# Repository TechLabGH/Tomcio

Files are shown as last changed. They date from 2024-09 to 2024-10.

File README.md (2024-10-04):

# Tomcio
**Film Development Timer/Controller/Helper**

The project has been built to help me in developing 35mm films. This process requires strictly following timeline depending on used chemicals and film recomendations.

It supports four stages (this is set for Ilford Delta 100 / Ilfosol-3 / Ilfostop Stop Bath / Rapid Fixer)

* **Development**

  Initial agitation during first 10 sec - invert tank 4 times. Next repeat this on beginning of every next minute. Total development time is 7:30

  Drain off developer 10 sec before end

* **Stop bath**

  I use 2 min stop bath with 4 tank inversions at the beginning and after 1 min

* **Fix**

  This is 4 min process - agitation is the same as in development.

* **Rinse**

  This is three step process - fill with water, invert tank 5 timex / replace water, invert 10 times / replace water, invert 20 times

Project use NEMA motor to invert tank. I built 3D printed mount where tank may be quickly and securely attached. I used 6 x 200mm 2020 profiles to build frame. Additionally there is vibration motor attached - it's running at the end of agitation to remove any bubles from film surface.

<a href="https://github.com/TechLabGH/Tomcio/blob/main/PCB/PCB%20design.html" target="blank">Here</a> is interactive PCB document with BOM. Download it and open from local disk.

Hardware/Software:
* <a href="https://www.amazon.com/dp/B0CKRJ81B5" target="blank">TFT Display</a> = 4.0 Inches 480x320 TFT Touch Screen LCD Display Module SPI ST7796S
* ESP32-S3-WROOM-1U-N16R8CT-ND

Software developed in PlatformIO with Arduino framework - libraries needed:
* bodmer/TFT_eSPI@^2.5.43
* laurb9/StepperDriver@^1.4.1

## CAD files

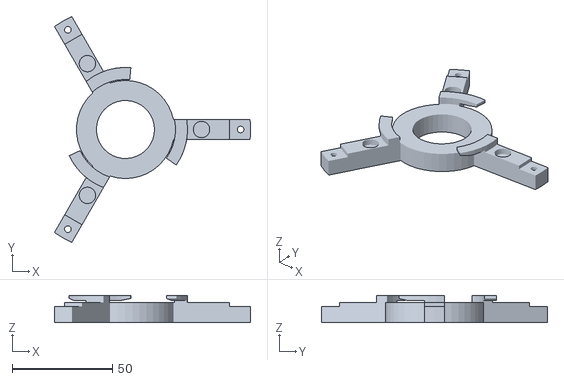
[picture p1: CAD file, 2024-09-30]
3D models/bottom.STL
98.0 x 112.9 x 13.5

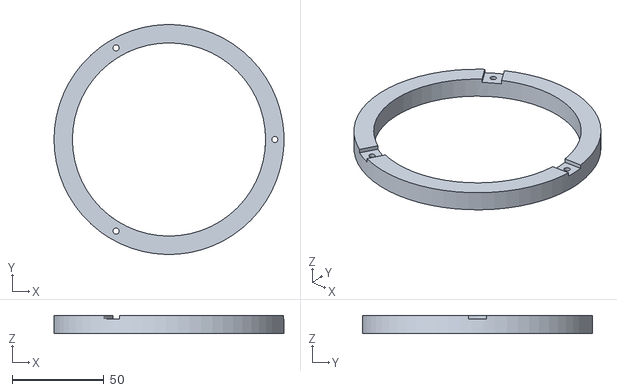
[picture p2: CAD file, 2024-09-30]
3D models/top.STL
125.0 x 125.0 x 10.0

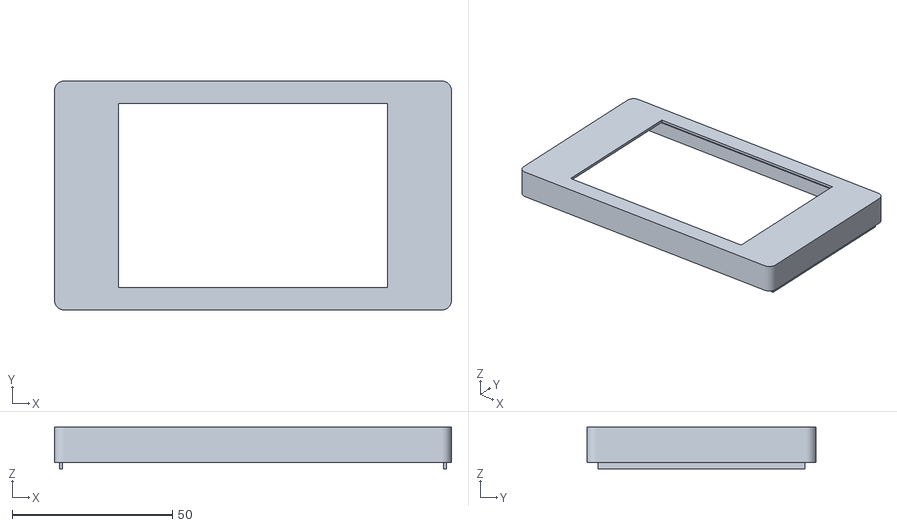
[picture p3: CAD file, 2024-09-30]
3D models/case_1.STL
124.0 x 71.5 x 13.0

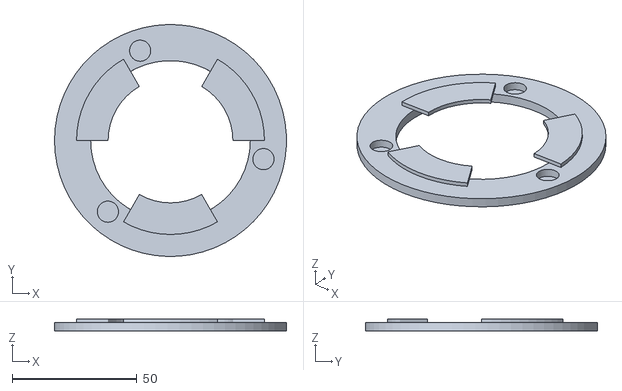
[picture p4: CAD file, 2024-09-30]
3D models/koreks.STL
93.0 x 93.0 x 5.00

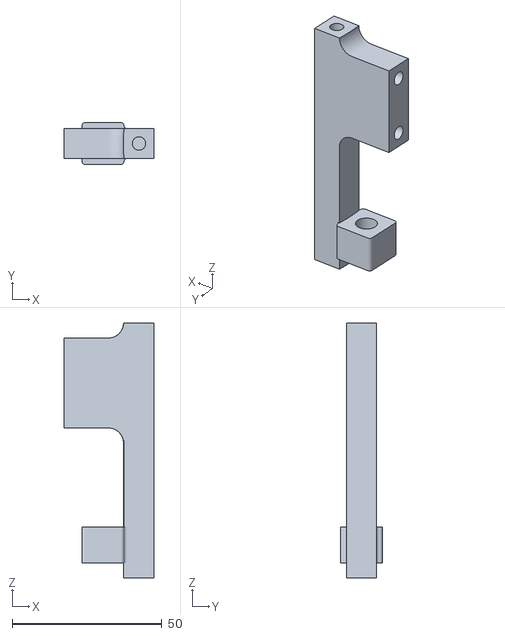
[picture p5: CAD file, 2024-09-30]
3D models/side2.STL
30.0 x 14.0 x 85.0

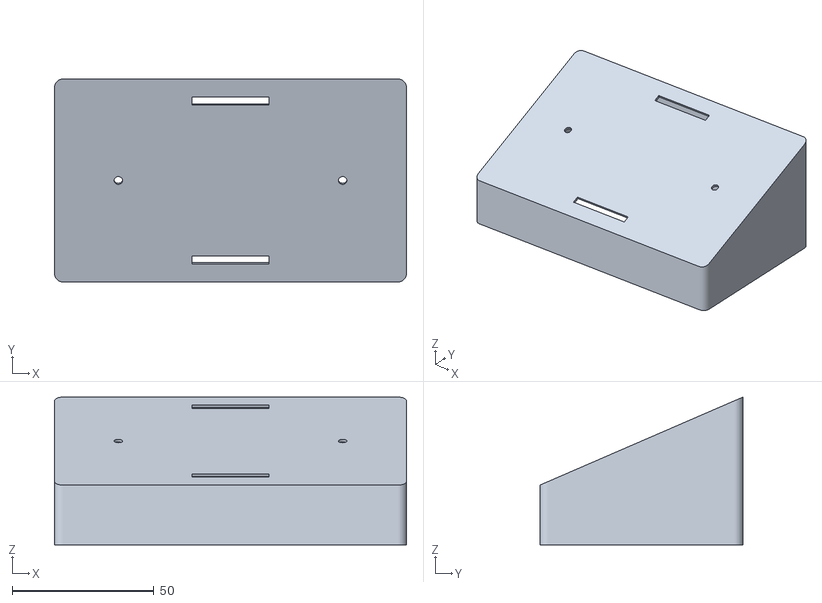
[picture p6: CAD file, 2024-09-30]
3D models/case_2.STL
124.0 x 71.5 x 52.1

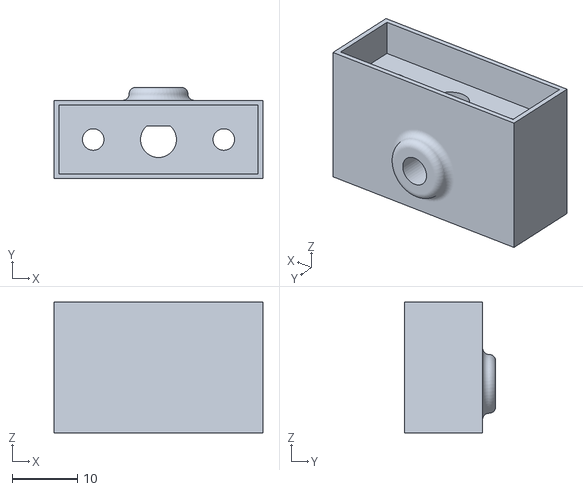
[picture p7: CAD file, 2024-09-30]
3D models/mount.STL
32.0 x 14.0 x 20.0

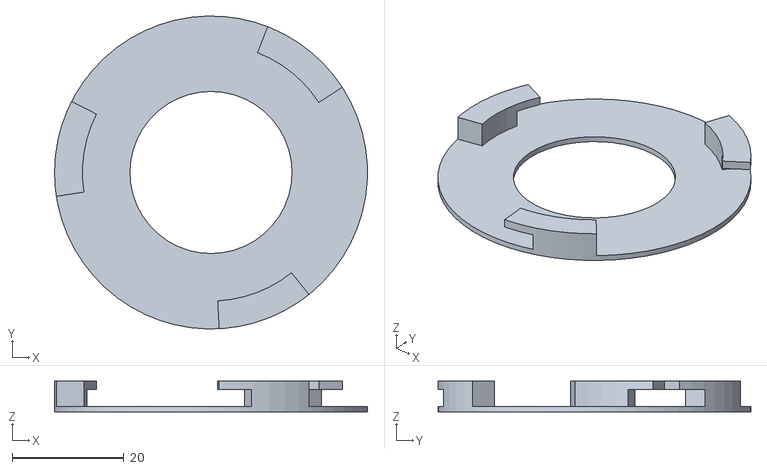
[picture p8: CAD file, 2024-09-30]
3D models/uchwyt.STL
56.0 x 56.0 x 5.50

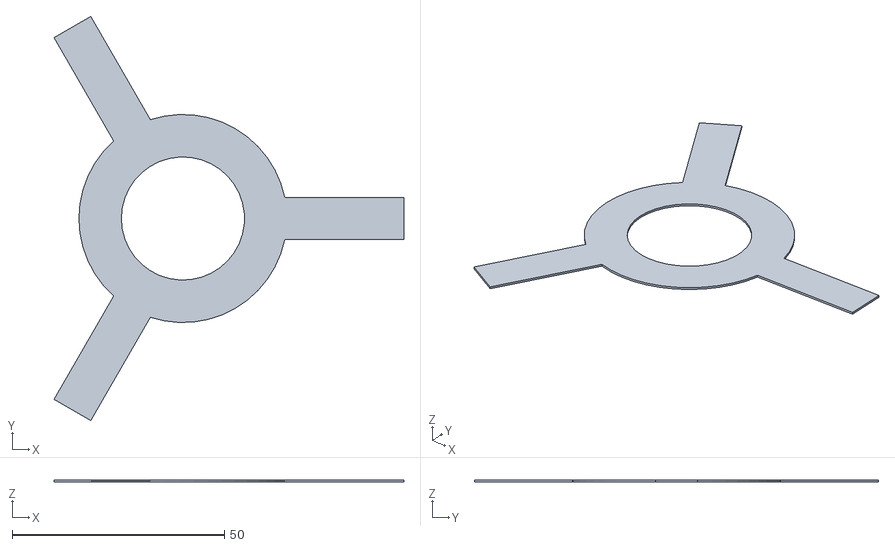
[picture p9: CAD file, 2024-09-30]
3D models/bottom_cover.STL
82.4 x 95.2 x 0.5

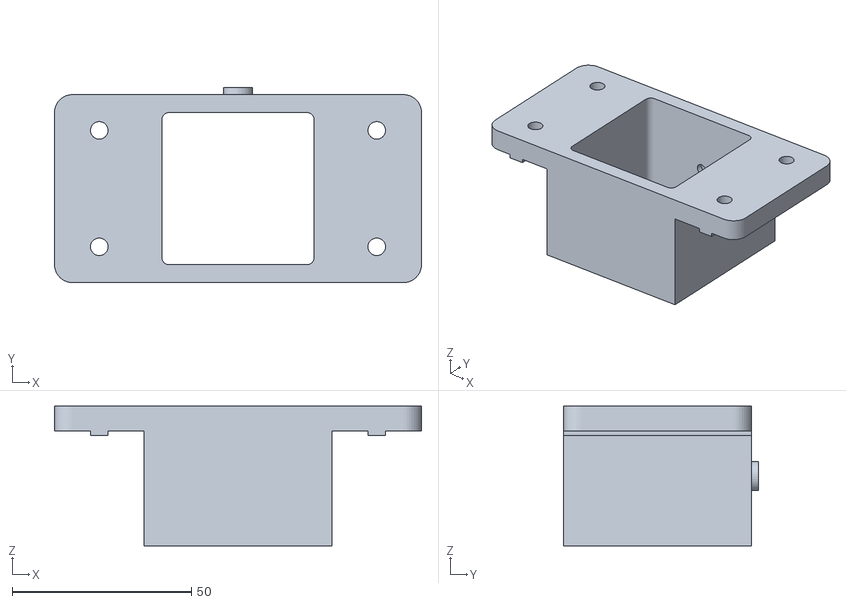
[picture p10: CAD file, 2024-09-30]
3D models/nema_mount.STL
102.5 x 54.5 x 39.0

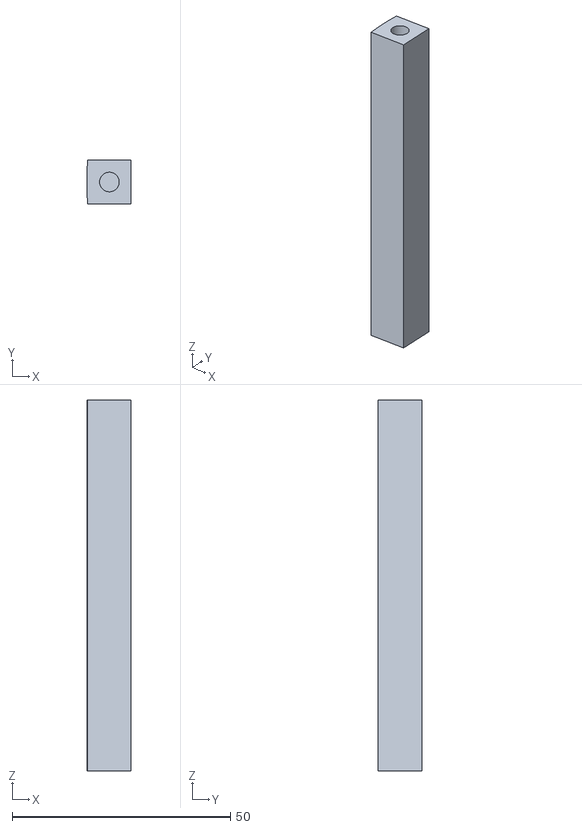
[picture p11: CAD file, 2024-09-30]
3D models/side1.STL
10.2 x 10.0 x 85.0

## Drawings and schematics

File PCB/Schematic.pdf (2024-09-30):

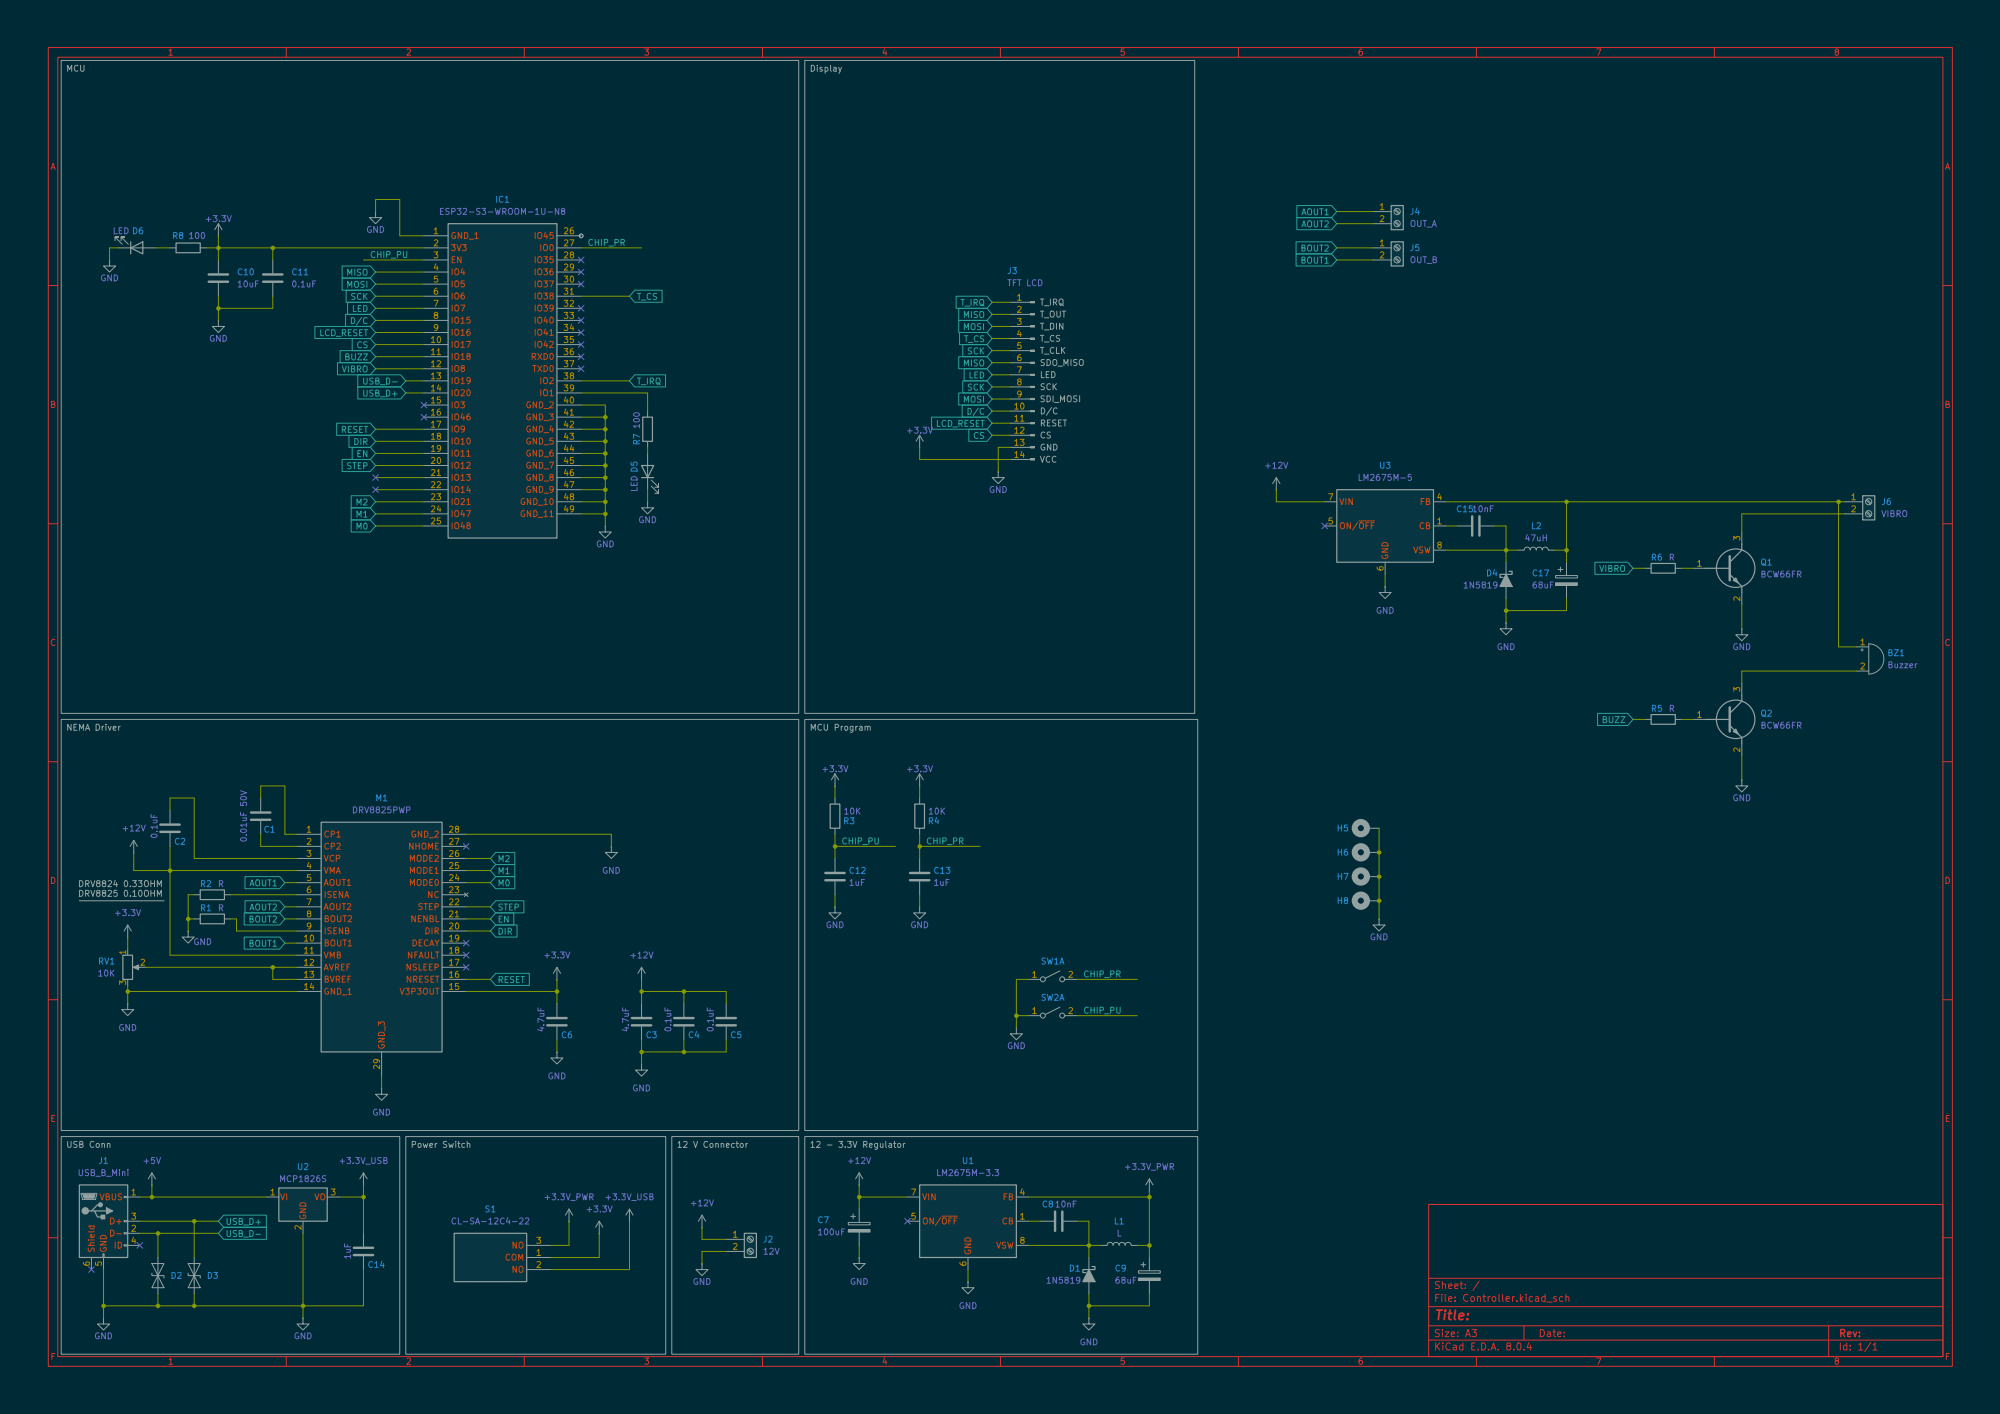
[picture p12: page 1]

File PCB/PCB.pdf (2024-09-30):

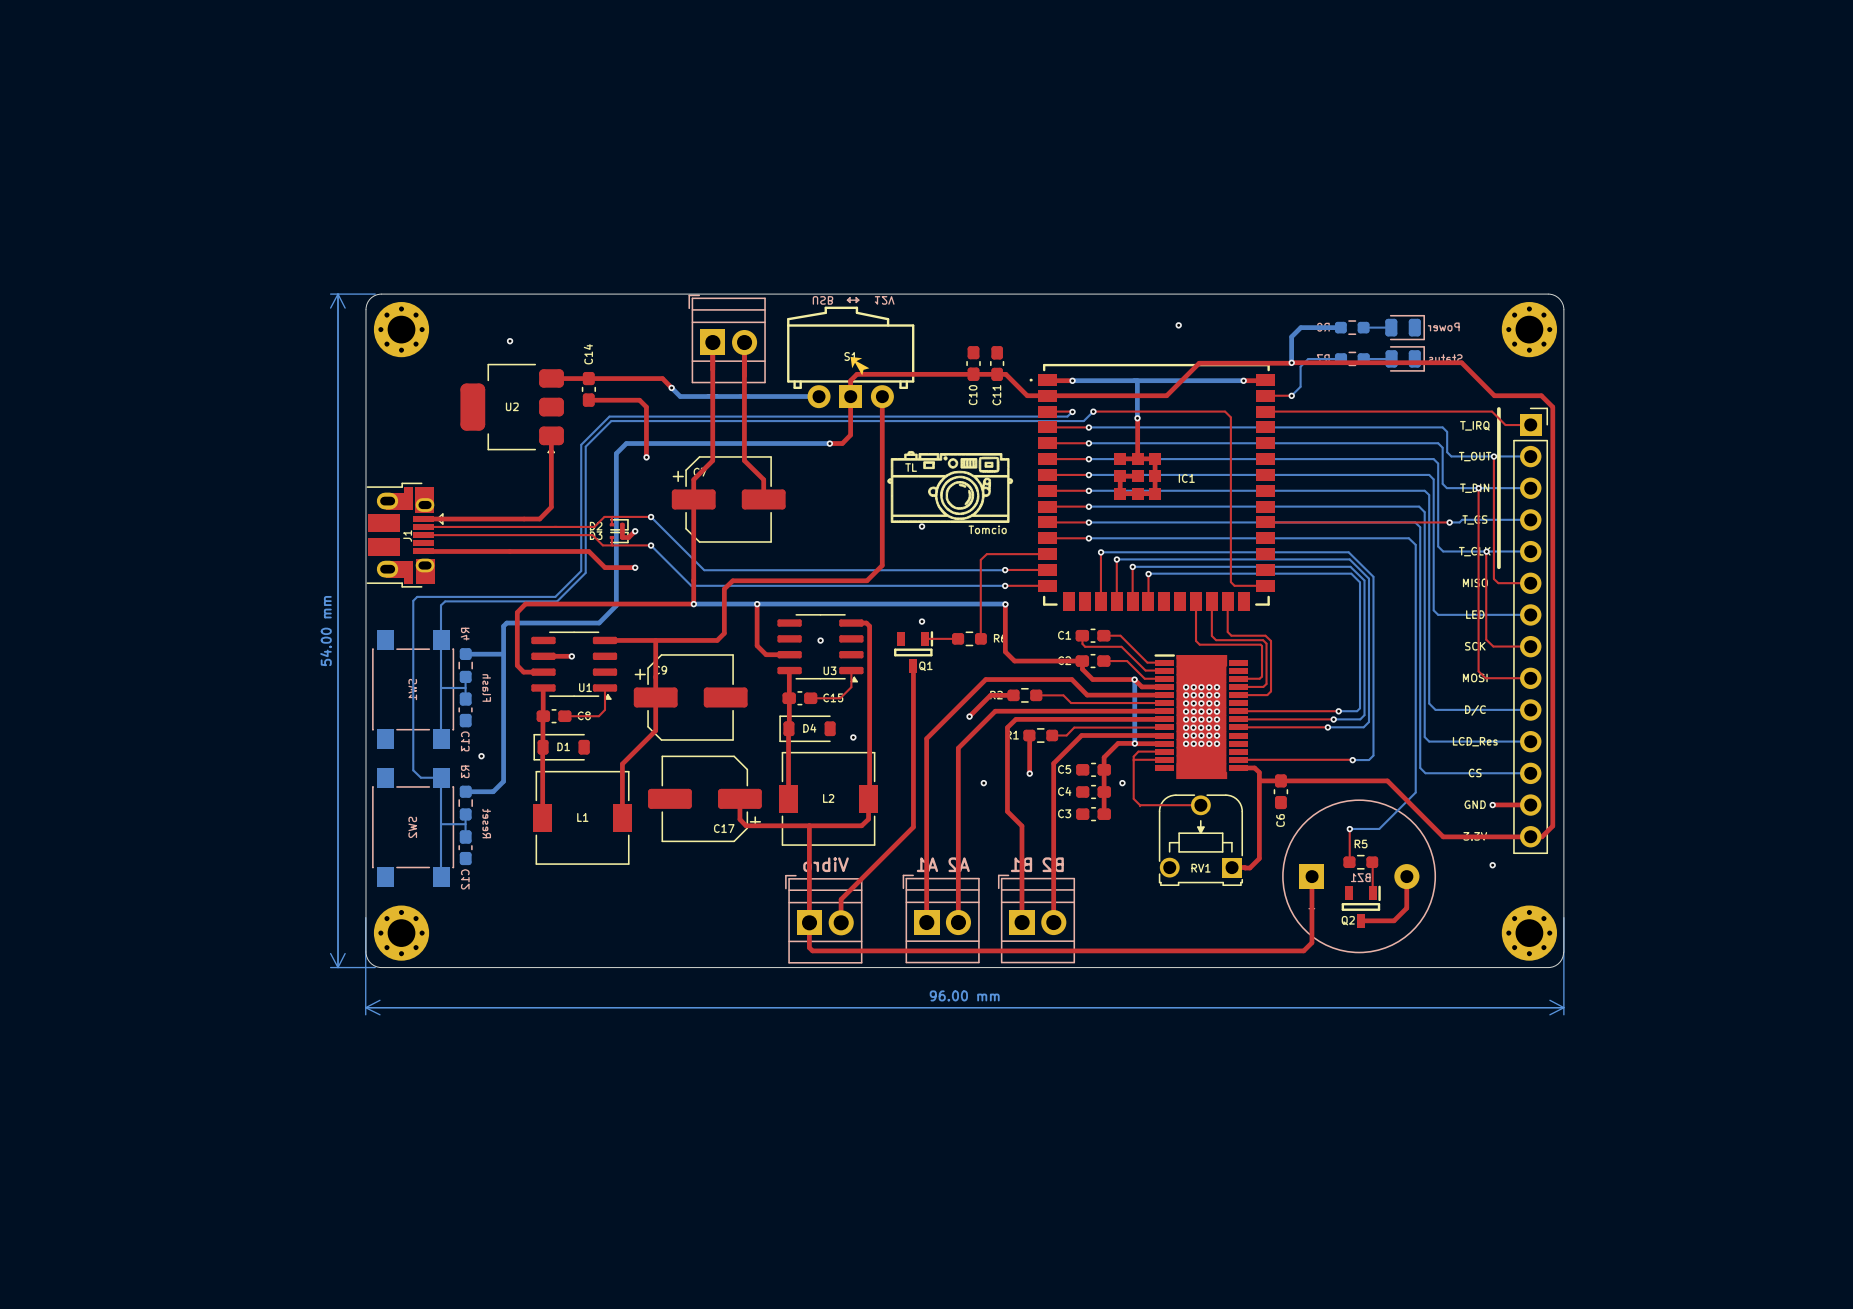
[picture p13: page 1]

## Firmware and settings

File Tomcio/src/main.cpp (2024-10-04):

#include <Arduino.h>
#include "FS.h"
#include <SPI.h>
#include <TFT_eSPI.h>    
#include "Free_Fonts.h"

TFT_eSPI tft = TFT_eSPI(); 

uint16_t prog_data[9][17];                       // Programs data
uint8_t sel_p;                                   // Selected program
uint32_t scale;                                  // Scale to display progress maker
unsigned long startTime;                         // Timestamp when step was started
unsigned long endTime;                           // Timestamp when step will end
unsigned long agitTime;                          // Timestamp of next agitation
unsigned long curr_time;                         // Curr time to calc display progress maker
uint8_t vibro = 0;                               // controlls vibration

#define CALIBRATION_FILE "/TouchCalData2"        // Calibration file
#define REPEAT_CAL false                         // Setting True will run calibration every time

//---------------------------------Stepper driver---------------------------------
#include "DRV8825.h"
// Motor steps per revolution. Most steppers are 200 steps or 1.8 degrees/step
#define MOTOR_STEPS 200
#define RPM         20
#define DIR         10
#define STEP        12
#define MODE0       48
#define MODE1       47
#define MODE2       21
#define ENABLE      11
#define MICROST     16
#define MOTOR_ACCEL 1000
#define MOTOR_DECEL 1000
DRV8825 stepper(MOTOR_STEPS, DIR, STEP, ENABLE, MODE0, MODE1, MODE2);

//=================================TIMER=================================

volatile bool tick = 0;
hw_timer_t *Timer0_Cfg = NULL;

void IRAM_ATTR Timer0_ISR(){
    tick = 1;
    if(vibro > 0){
        vibro--;
    } else   digitalWrite(8, LOW);
}

// function declarations
  void init_SPIFFS();
  void touch_calibrate();
  void load_programs();
  void read_prog();
  void edit_prog(int prog);
  void sel_prog();
  void irig(int ir_cnt);
  void tft_upd();
  void dev_stage();
  void stop_stage();
  void fix_stage();
  void rinse_stage();

//=================================SETUP=================================

void setup() {

  Serial.begin(115200);

  // define pins
    pinMode(8,  OUTPUT);       // vibration
    pinMode(18, OUTPUT);      // buzzer
    pinMode(1,  OUTPUT);       // status led

  // Init screen
    tft.init();
    tft.setRotation(1);
  
  // Init SPIFFS
  init_SPIFFS();

  // Initial functions
    //load_programs();    <<== uncomment to initially load programs
    read_prog();
    touch_calibrate();

  // Turn on status LED - all initials done
  digitalWrite(1, HIGH);

  // Welcome screen
    tft.fillScreen(TFT_BLACK);
    tft.setTextSize(2);
    tft.setFreeFont(FF32);
    tft.setTextColor(TFT_GREEN, TFT_BLACK);
    tft.setTextDatum(MC_DATUM);
    tft.drawString("Tomcio", tft.width() / 2, tft.height() / 2);
    tft.setTextColor(TFT_WHITE, TFT_BLACK);
    tft.setTextSize(1);
    tft.setFreeFont(FF29);
    tft.drawString("Universal film development helper", tft.width() / 2, tft.height() / 2 + 60);
    tft.setFreeFont(FF17);
    tft.drawString("Set tank holder in position", tft.width() / 2, tft.height() / 2 + 120);
    delay(10000);
    tft.fillScreen(TFT_BLACK);

  // Motor config
    stepper.begin(RPM);
    stepper.setMicrostep(MICROST);
    stepper.setEnableActiveState(LOW);
    stepper.enable();
    stepper.setSpeedProfile(stepper.LINEAR_SPEED, MOTOR_ACCEL, MOTOR_DECEL);

  // Timer config
    Timer0_Cfg = timerBegin(0, 8000, true);
    timerAttachInterrupt(Timer0_Cfg, &Timer0_ISR, true);
    timerAlarmWrite(Timer0_Cfg, 5000, true);
    timerAlarmEnable(Timer0_Cfg);

  // Execute program
    sel_prog();
    dev_stage();
    stop_stage();
    fix_stage();
    rinse_stage();
}

//=================================ENDLESS LOOP=================================

void loop(void) {
  tft.fillScreen(TFT_BLACK);
  tft.setFreeFont(FF32);
  tft.setTextColor(TFT_GREEN, TFT_BLACK);
  tft.setTextDatum(MC_DATUM);
  tft.setTextSize(2);
  tft.drawString("DONE", tft.width() / 2, tft.height() / 2);

  while(1){}
}

//=================================INITIAL FUNCTIONS=================================

//---------------------------------Init SPIFFS---------------------------------
void init_SPIFFS(){
  if (!SPIFFS.begin()) {
    Serial.println("formatting file system");
    SPIFFS.format();
    SPIFFS.begin();
  }else Serial.println("file system formatted already");
}

//---------------------------------Touchscreen calibration---------------------------------
void touch_calibrate(){

  uint16_t calData[5];
  uint8_t calDataOK = 0;

  // check if calibration file exists and size is correct
  if (SPIFFS.exists(CALIBRATION_FILE)) {
    if (REPEAT_CAL)
    {
      // Delete if we want to re-calibrate
      SPIFFS.remove(CALIBRATION_FILE);
    }
    else
    {
      File f = SPIFFS.open(CALIBRATION_FILE, "r");
      if (f) {
        if (f.readBytes((char *)calData, 14) == 14)
          calDataOK = 1;
        f.close();
      }
    }
  }

  if (calDataOK && !REPEAT_CAL) {
    // calibration data valid
    tft.setTouch(calData);
  } else {
    // data not valid so recalibrate
    tft.fillScreen(TFT_BLACK);
    tft.setCursor(20, 0);
    tft.setTextFont(2);
    tft.setTextSize(1);
    tft.setTextColor(TFT_WHITE, TFT_BLACK);

    tft.println("Touch corners as indicated");

    tft.setTextFont(1);
    tft.println();

    if (REPEAT_CAL) {
      tft.setTextColor(TFT_RED, TFT_BLACK);
      tft.println("Set REPEAT_CAL to false to stop this running again!");
    }

    tft.calibrateTouch(calData, TFT_MAGENTA, TFT_BLACK, 15);

    tft.setTextColor(TFT_GREEN, TFT_BLACK);
    tft.println("Calibration complete!");

    // store data
    File f = SPIFFS.open(CALIBRATION_FILE, "w");
    if (f) {
      f.write((const unsigned char *)calData, 14);
      f.close();
    }
  }
}

//---------------------------------Load initial program to SPFIFS---------------------------------
void load_programs(){

   if (!SPIFFS.exists("/Program_1")) {
    Serial.println("Writting Program_1");
    File f = SPIFFS.open("/Program_1", "w");
    uint16_t prog_data[17] = {4 , 450 , 4 , 60 , 6 , 120 , 6 , 60 , 4 , 240 , 4 , 60 , 5 , 10 , 20 , 0 , 0};
      uint8_t prog_data8[34];
      uint8_t z = 0;
      for (int i = 0; i < 17; i++) {
        prog_data8[z] = prog_data[i] & 0xff;
        prog_data8[z+1] = (prog_data[i] >> 8) & 0xff;
        z = z + 2;
      }
    if (f) {
      f.write(prog_data8, sizeof(prog_data8));
      f.close();
    }
   } else Serial.println("Program_1 exists");

  for (int p = 2; p<10; p++){
    String file_name = "/Program_"+String(p);

      if (!SPIFFS.exists(file_name)) {
      Serial.println("Writting " + file_name);
      File f = SPIFFS.open(file_name, "w");
      uint16_t prog_data[17] = {0 , 0 , 0 , 0 , 0 , 0 , 0 , 0 , 0 , 0 , 0 , 0 , 0 , 0 , 0 , 0 , 0};
        uint8_t prog_data8[34];
        uint8_t z = 0;
        for (int i = 0; i < 17; i++) {
          prog_data8[z] = prog_data[i] & 0xff;
          prog_data8[z+1] = (prog_data[i] >> 8) & 0xff;
          z = z + 2;
        }
      if (f) {
        f.write(prog_data8, sizeof(prog_data8));
        f.close();
      }
    } else Serial.println(file_name + " exists");
  }

}

//---------------------------------Read programs from SPFIFS---------------------------------
void read_prog(){

  uint8_t prog_data8[34];

  for (int pr = 0; pr < 9; pr = pr +1) {
    String file_name = "/Program_" + String(pr+1);
    File f = SPIFFS.open(file_name, "r");
    f.read(prog_data8, 34);
      int z = 0;
      for (int i = 0; i<17; i++){
        prog_data[pr][i] = prog_data8[z] + (prog_data8[z+1]<<8);
        z = z + 2;
      }
    f.close();
  }
}

//---------------------------------Edit selected program---------------------------------
void edit_prog(int prog){

  tft.fillScreen(TFT_BLACK);
  tft.setTextSize(2);
  tft.setTextColor(TFT_WHITE,TFT_BLACK);
  tft.setTextDatum(ML_DATUM);
  tft.drawString("Dev", 5, 60);
  tft.drawString("Stop", 5, 120);
  tft.drawString("Fix", 5, 180);
  tft.drawString("Rinse", 5, 260);
  tft.setTextDatum(MC_DATUM);
  tft.drawString("I-A", 140,10);
  tft.drawString("Time", 240,10);
  tft.drawString("A-C", 340,10);
  tft.drawString("A-T", 440,10);

  uint8_t prog_data_cnt = 0;

  for(uint8_t d = 1; d < 4; d++){
    for(uint8_t p = 1; p < 5; p++){

      tft.setTextColor(TFT_WHITE,TFT_BLACK);
      tft.drawString(String(prog_data[prog-1][prog_data_cnt]),(p *100) + 40,d * 60);
      prog_data_cnt++;

      tft.setTextColor(TFT_RED,TFT_WHITE);
      tft.drawString("-",(p *100) + 10,d * 60);
      tft.setTextColor(TFT_BLUE,TFT_WHITE);
      tft.drawString("+",(p *100) + 70,d * 60);

    }
  }

  for(uint8_t d = 0; d < 5; d++){

    tft.setTextColor(TFT_WHITE,TFT_BLACK);
    tft.drawString(String(prog_data[prog-1][12 + d]),140 + (d * 75),260);
    tft.setTextColor(TFT_RED,TFT_WHITE);
    tft.drawString("-",115 + (d * 75),260);
    tft.setTextColor(TFT_BLUE,TFT_WHITE);
    tft.drawString("+",165 + (d * 75),260);

  }

  tft.setTextColor(TFT_BLACK,TFT_GREEN);
  tft.setTextDatum(BL_DATUM);
  tft.drawString("SAVE",10,320);
  tft.setTextColor(TFT_BLACK,TFT_YELLOW);
  tft.setTextDatum(BR_DATUM);
  tft.drawString("CANCEL",470,320);

  uint16_t x, y;
  uint8_t ret_res = 0;
  tft.setTextColor(TFT_WHITE,TFT_BLACK);
  tft.setTextSize(2);
  tft.setTextDatum(MC_DATUM);

  do{  
    while(!tft.getTouch(&x, &y)){
      delay(5);
    }

    uint8_t prog_data_cnt = 0;

    for(uint8_t d = 1; d < 4; d++){
      for(uint8_t p = 1; p < 5; p++){

        if ((x > (p * 100)) && (x < (p * 100) + 20) && (y > (d * 60) - 10) && (y < (d * 60) + 10)) {
          if(prog_data[prog-1][prog_data_cnt]>0) prog_data[prog-1][prog_data_cnt]--;
          tft.drawString("    ", (p * 100) + 40, d * 60);
          tft.drawString(String(prog_data[prog-1][prog_data_cnt]), (p *100) + 40, d * 60);
        }

        if ((x > (p * 100) + 60) && (x < (p *100) + 80) && (y > (d * 60) - 10) && (y < (d * 60) + 10)) {
          prog_data[prog-1][prog_data_cnt]++;
          tft.drawString("    ", (p * 100) + 40, d * 60);
          tft.drawString(String(prog_data[prog-1][prog_data_cnt]), (p *100) + 40, d * 60);
        }
      prog_data_cnt++;
      }
    }

    for(uint8_t d = 0; d < 5; d++){

      if ((x > 105 + (d * 75)) && (x < 125 + (d * 75)) && (y > 250) && (y < 270)) {
        if(prog_data[prog-1][12 + d]>0) prog_data[prog-1][12 + d]--;
        tft.drawString("   ", 140 + (d * 75), 260);
        tft.drawString(String(prog_data[prog-1][12 + d]), 140 + (d * 75), 260);
      }

      if ((x > 155 + (d * 75)) && (x < 175 + (d * 75)) && (y > 250) && (y < 270)) {
        prog_data[prog-1][12 + d]++;
        tft.drawString("   ", 140 + (d * 75), 260);
        tft.drawString(String(prog_data[prog-1][12 + d]), 140 + (d * 75), 260);
      }

    }

    if ((x > 9) && (x < 55) && (y > 300) && (y < 321)) {
      ret_res =1;
    }

    if ((x > 425) && (x < 471) && (y > 300) && (y < 321)) {
      ESP.restart();
    }

    delay(30);
  } while(ret_res == 0);

  //save

  tft.setTextDatum(MC_DATUM);
  tft.setTextFont(1);
  tft.setTextColor(TFT_RED,TFT_BLACK);
  tft.setTextSize(5);
  tft.drawString("SAVING",240,160);

    String file_name = "/Program_"+String(prog);
      SPIFFS.remove(file_name);

      if (!SPIFFS.exists(file_name)) {
      Serial.println("Opening " + file_name);
      File f = SPIFFS.open(file_name, "w");

        if (!f) {
            Serial.println("Failed to open file for writing");
        } else {
            Serial.println("File opened for writing");
        }

        uint8_t prog_data8[34];
        uint8_t z = 0;
        for (int i = 0; i < 17; i++) {
          prog_data8[z] = prog_data[prog-1][i] & 0xff;
          prog_data8[z+1] = (prog_data[prog-1][i] >> 8) & 0xff;
          z = z + 2;
        }
      if (f) {
        f.write(prog_data8, sizeof(prog_data8));
        f.close();
      }
    } 

    delay(5000);

    ESP.restart();

}

//---------------------------------Display program init screen---------------------------------
void sel_prog(){

  int prog = 1;
  bool set = 0;

  tft.setTextSize(1);
  tft.setFreeFont(FF22);
  tft.setTextColor(TFT_YELLOW, TFT_BLACK);
  tft.drawString("Select program", tft.width() / 2, 15);
  tft.drawLine(0,40,480,40,TFT_WHITE);
  tft.fillTriangle(20,270,63,300,63,240,TFT_BLUE);
  tft.fillTriangle(460,270,417,300,417,240,TFT_BLUE);
  tft.fillRect(130,240,220,60,TFT_GREEN);
  tft.setTextDatum(MC_DATUM);
  tft.setFreeFont(FF5);
  tft.setTextColor(TFT_RED,TFT_BLACK);
  tft.drawString("Edit",450,55);
  tft.setTextSize(1);
  tft.setFreeFont(FF22);
  tft.setTextColor(TFT_BLACK, TFT_GREEN);
  tft.drawString("LOAD", tft.width() / 2, 270);
  tft.setTextFont(1);
  tft.setTextDatum(TL_DATUM);

  do {

    tft.setTextColor(TFT_RED, TFT_BLACK);
    tft.drawString("Program: " + String(prog),15,45);
    tft.setTextColor(TFT_WHITE, TFT_BLACK);
    tft.drawString("DEVELOPMENT",25,60);
    tft.drawString("Initial agitation: " + String(prog_data[prog-1][0]) + " rotation(s)",35,75);
    tft.drawString("Develop for " + String(prog_data[prog-1][1]) + "s with " + String(prog_data[prog-1][2]) + " rotation(s) every " + String(prog_data[prog-1][3]) +"s",35,90);
    tft.drawString("STOP BATH",25,105);
    tft.drawString("Initial agitation: " + String(prog_data[prog-1][4]) + " rotation(s)",35,120);
    tft.drawString("Bath for " + String(prog_data[prog-1][5]) + "s with " + String(prog_data[prog-1][6]) + " rotation(s) every " + String(prog_data[prog-1][7]) +"s",35,135);
    tft.drawString("FIX",25,150);
    tft.drawString("Initial agitation: " + String(prog_data[prog-1][8]) + " rotation(s)",35,165);
    tft.drawString("Bath for " + String(prog_data[prog-1][9]) + "s with " + String(prog_data[prog-1][10]) + " rotation(s) every " + String(prog_data[prog-1][11]) +"s",35,180);
    tft.drawString("RINSE",25,195);
    tft.drawString("Pattern: " + String(prog_data[prog-1][12]) + " - " + String(prog_data[prog-1][13]) + " - " + String(prog_data[prog-1][14]) + " - " + String(prog_data[prog-1][15]) + " - " + String(prog_data[prog-1][16]) + " rotation(s)",35,210);

    uint16_t x, y;
    while(!tft.getTouch(&x, &y)){
      delay(5);
    }

    if ((x > 20) && (x < 63)) {
      if ((y > 240) && (y < 300)) {
        prog = prog - 1;
        if (prog == 0) prog = 9;
        tft.fillRect(0,41,420,174,TFT_BLACK);
        delay(15);
      }
    }

    if ((x > 417) && (x < 460)) {
      if ((y > 240) && (y < 300)) {
        prog = prog + 1;
        if (prog == 10) prog = 1;
        tft.fillRect(0,41,420,174,TFT_BLACK);
        delay(15);
      }
    }

    if ((x > 130) && (x < 350)) {
      if ((y > 240) && (y < 300)) {
        set = 1;
        delay(15);
      }
    }

    if ((x > 430) && (x < 470)) {
      if ((y > 50) && (y < 60)) {
        edit_prog(prog);
      }
    }

  } while(set == 0);

  sel_p = prog - 1;
}

//=================================DEVELOP FUNCTIONS=================================

//---------------------------------Development---------------------------------
void irig(int ir_cnt){
  tft.fillRect(0,145,480,160,TFT_BLACK);
  tft.setTextSize(1);
  tft.setTextColor(TFT_GREEN, TFT_GREEN);
  tft.setTextDatum(MC_DATUM);
  tft.drawString("Agitation", tft.width() / 2, 225);
  
  int8_t direc = 1;
  for( uint8_t i = 0; i < ir_cnt; i++){
    stepper.rotate(90 * direc);
    delay(125);
    stepper.rotate(-90 * direc);
    delay(125);
    direc = direc * (-1);
  }

  tft.fillRect(0,145,480,160,TFT_BLACK);
  tft.setTextSize(2);
  tft.setTextColor(TFT_GREEN, TFT_GREEN);
  tft.drawString("WAIT", tft.width() / 2, 225);

  digitalWrite(8, HIGH);
  vibro = 6;
}

void tft_upd(){
  tft.setTextColor(TFT_GOLD, TFT_BLACK);
  tft.setTextDatum(MR_DATUM);
  tft.setFreeFont(FF6);
  tft.setTextSize(1);
  tft.fillRect(300,0,180,40,TFT_BLACK);
  curr_time = millis();
  int m = ((endTime - curr_time)/1000) / 60;
  int s = ((endTime - curr_time)/1000) % 60;
  if (s < 10) tft.drawString(String(m) + ":0" + String(s), 475, 20);
  else tft.drawString(String(m) + ":" + String(s), 475, 20);
  tft.fillRect(20,92,440,9,TFT_BLACK);
  tft.fillTriangle(((curr_time-startTime)*scale/100000L)+30,93,((curr_time-startTime)*scale/100000L)+35,100,((curr_time-startTime)*scale/100000L)+25,100,TFT_CYAN);
}

void dev_stage(){
  tft.fillScreen(TFT_BLACK);

  tft.setFreeFont(FF22);
  tft.setTextColor(TFT_RED, TFT_BLACK);
  tft.setTextDatum(ML_DATUM);
  tft.setTextSize(1);
  tft.drawString("DEVELOPMENT", 20, 20);
  tft.setTextDatum(MR_DATUM);
  tft.setFreeFont(FF6);
  tft.setTextSize(1);
  int m = prog_data[sel_p][1] / 60;
  int s = prog_data[sel_p][1] % 60;
  if (s < 10) tft.drawString(String(m) + ":0" + String(s), 475, 20);
  else tft.drawString(String(m) + ":" + String(s), 475, 20);
  tft.drawLine(0,47,480,47,TFT_WHITE);
  tft.drawRect(29,69,422,22,TFT_WHITE);
  scale = 42000/(prog_data[sel_p][1]);
  tft.fillRect(450-(0.1*scale),70,(0.1*scale),20,TFT_RED);
  uint16_t t = prog_data[sel_p][3] + 1;
  do {
    tft.fillRect(30 + (t*scale/100),70,(prog_data[sel_p][2] * 2.5 * scale/100),20,TFT_YELLOW);
    t=t+prog_data[sel_p][3];
  } while(t < prog_data[sel_p][1]);
  tft.fillRect(30,70,((prog_data[sel_p][3] - prog_data[sel_p][0] *2.5) * scale/100),20,TFT_GREEN);
  tft.fillTriangle(29,93,34,100,24,100,TFT_CYAN);

  tft.fillSmoothRoundRect(130,150,220,150,10,TFT_GREEN,TFT_WHITE);

  tft.setTextSize(2);
  tft.setFreeFont(FF22);
  tft.setTextColor(TFT_BLACK, TFT_GREEN);
  tft.setTextDatum(MC_DATUM);
  tft.drawString("START", tft.width() / 2, 225);

  bool click = 0;
  while(click == 0){

    uint16_t x, y;
    while(!tft.getTouch(&x, &y)){
      delay(5);
    }

    if ((x > 130) && (x < 350)) {
      if ((y > 150) && (y < 300)) {
        click = 1;
        delay(15);
      }
    }
  }

  startTime = millis();
  endTime   = startTime + prog_data[sel_p][1] * 1000;
  agitTime  = startTime + prog_data[sel_p][3] * 1000;
  curr_time = startTime;

  tft.fillSmoothRoundRect(130,150,220,150,10,TFT_LIGHTGREY,TFT_WHITE);
  tft.setTextSize(2);
  tft.setFreeFont(FF22);
  tft.setTextColor(TFT_BLACK, TFT_LIGHTGREY);
  tft.setTextDatum(MC_DATUM);
  tft.drawString("START", tft.width() / 2, 225);

  delay(1000);

  tft.fillSmoothRoundRect(130,150,220,150,10,TFT_GREEN,TFT_WHITE);
  tft.setTextSize(1);
  tft.setTextColor(TFT_BLACK, TFT_GREEN);
  tft.drawString("Initial", tft.width() / 2, 210);
  tft.drawString("agitation", tft.width() / 2, 240);

  click = 0;
  while(click == 0){

    uint16_t x, y;
    while(!tft.getTouch(&x, &y)){
      if (tick){
        tft_upd();
        tick = 0;
      }
    }

    if ((x > 130) && (x < 350)) {
      if ((y > 150) && (y < 300)) {
        click = 1;
        delay(15);
      }
    }
  }

  irig(prog_data[sel_p][0]);


  bool drain = 1;
  while(millis() < endTime){
  
    if (millis() > agitTime){
      irig(prog_data[sel_p][2]);
      agitTime  = agitTime + prog_data[sel_p][3] * 1000;
    }
  
    if (millis() > endTime - 10000 && drain){
      digitalWrite(18, HIGH);
      tft.fillRect(0,145,480,160,TFT_BLACK);
      tft.setTextSize(2);
      tft.setTextColor(TFT_RED, TFT_BLACK);
      tft.setTextDatum(MC_DATUM);
      tft.drawString("DRAIN OFF", tft.width() / 2, 225);
      drain = 0;
    }

    if (tick){
      tft_upd();
      tick = 0;
    }
  }
  digitalWrite(18, LOW);
  tft.fillRect(0,145,480,160,TFT_BLACK);
  tft.setTextSize(1);
  tft.setTextColor(TFT_YELLOW, TFT_BLACK);
  tft.setTextDatum(MC_DATUM);
  tft.drawString("DEVELOPMENT DONE", tft.width() / 2, 225);
  delay(5000);

}
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
